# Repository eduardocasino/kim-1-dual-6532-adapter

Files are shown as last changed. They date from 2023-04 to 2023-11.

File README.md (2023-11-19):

# KIM-1 Dual 6530-6532 adapter

## Introduction

Welcome to the KIM-1 Dual 6530-6532 adapter repository. This adapter replaces both 6530 chips on the KIM-1 with a single board that contains a couple of 6532 chips, an EPROM and a few logic ICs.

As far as I know, this is the only board that allows you to replace both 6530 chips simultaneously.

## About

I designed this board for [my KIM-1 PCB replica](https://github.com/eduardocasino/kim-1), but it will also work with real KIM-1s that have both RRIOTs missing or broken.

The schematic is based on Ruud Baltissen's KIM-1 replica, with very minor modifications. The PCB features hand-traced tracks to seamlessly integrate with the KIM-1 board:

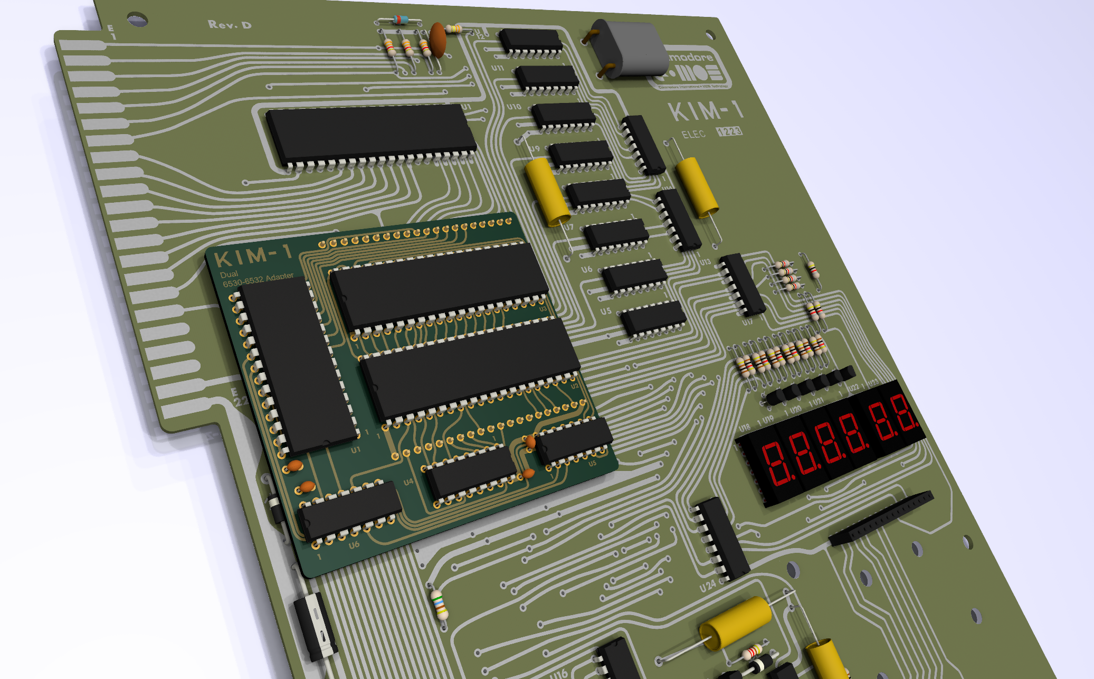
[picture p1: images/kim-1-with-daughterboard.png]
board installed


~~WARNING: I have not yet sent the board to fabrication, so it is untested!~~

The board has been successfully tested with my [my KIM-1 replica](https://github.com/eduardocasino/kim-1)

## Programming the EPROM

You can get the ROM contents from [Hans Otten's site](http://retro.hansotten.nl/6502-sbc/kim-1-manuals-and-software/kim_1-roms/)

There are two sets available: One that uses $00 as filler bytes and another that uses $FF. Both work equally well, but the one with $00 is what the original KIM-1 has. To program the EPROM:

1. Download "6530-002 fillerbyte00.bin" and "6530-003 fillerbyte00.bin" from Hans Otten's site (replace FF with 00 if you wish)
"6530-003 fillerbyte00.bin" has the ROM contents from $1800 to $1BFF and
"6530-002 fillerbyte00.bin" from $1C00 to $1FFF

2. Concat both files:

~~~
$ cat "6530-003 fillerbyte00.bin" "6530-002 fillerbyte00.bin" > KIM-1-ROM.bin
~~~

3. Program the EPROM with the resulting file starting at address $1800

## Licensing

This is a personal project that I am sharing in case it is of interest to any retrocomputing enthusiast and all the information in this repository is provided "as is", without warranty of any kind. I am not liable for any damages that may occur, whether it be to individuals, objects, KIM-1 computers, kittens or any other pets. It should also be noted that this design has not been tested and may contain errors, therefore anyone who chooses to use it does so at their own risk.



This work is licensed under a [Creative Commons Attribution-NonCommercial 4.0 International License](http://creativecommons.org/licenses/by-nc/4.0/).

EXCEPTION: The electrical schematic and all the associated symbols are licensed under a [Creative Commons Attribution 4.0 International License](https://creativecommons.org/licenses/by/4.0/).

See the LICENSE.md file for details.

## Changelog
#### 05/05/2023
* Fix tracks that were not well imported from svg
#### 09/04/2023
* Make ROM content available on phi2 only
* Add decoupling capacitor to ROM chip

## Acknowledgements

* Hans Otten and his [Retro Computing blog](http://retro.hansotten.nl/). Everything you need to know about the RRIOT and RIOT.
* Ruud Baltissen for [the original schematic](http://www.baltissen.org/newhtm/buildkim.htm).
* Frank Wolf and Dieter a.k.a. ttlworks for their [6530-004 dissection](http://forum.6502.org/viewtopic.php?f=4&t=6711) (Also [here](http://retro.hansotten.nl/6502-sbc/tim-6530-004/6530-004-dissected/)).

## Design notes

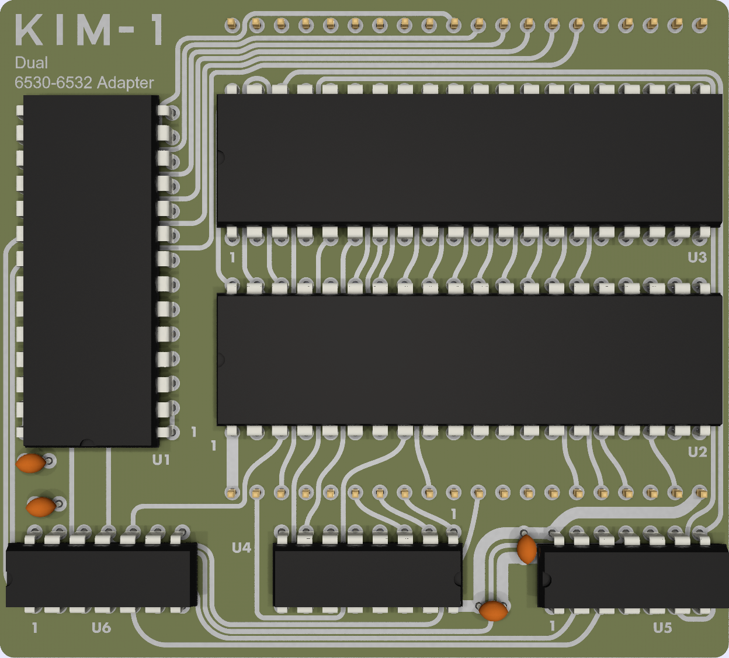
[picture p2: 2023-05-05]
images/kim-1-dual-6532-adapter-comp.png

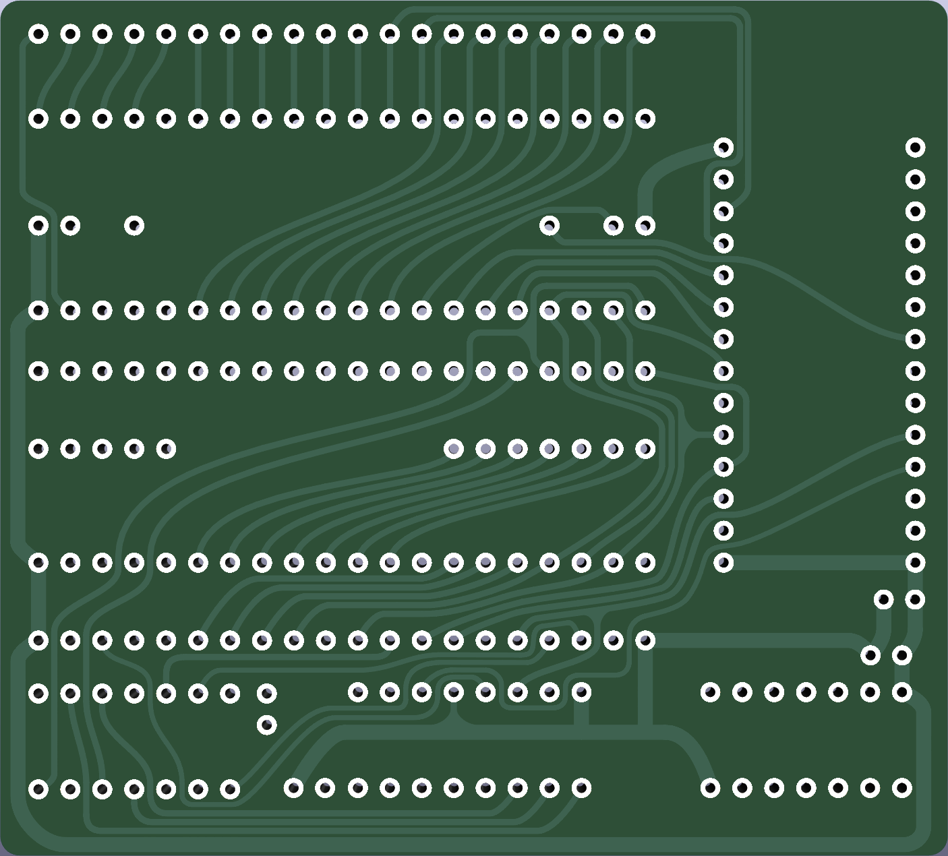
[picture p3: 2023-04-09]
images/kim-1-dual-6532-adapter-back.png

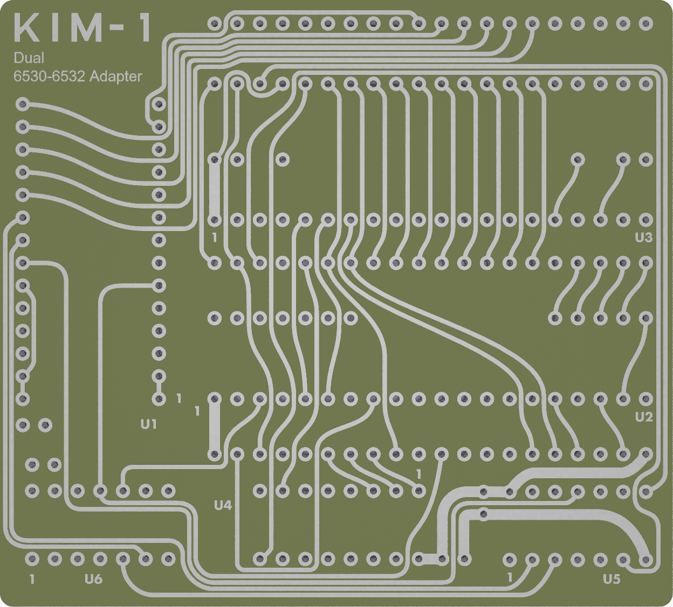
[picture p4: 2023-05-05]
images/kim-1-dual-6532-adapter-front.png

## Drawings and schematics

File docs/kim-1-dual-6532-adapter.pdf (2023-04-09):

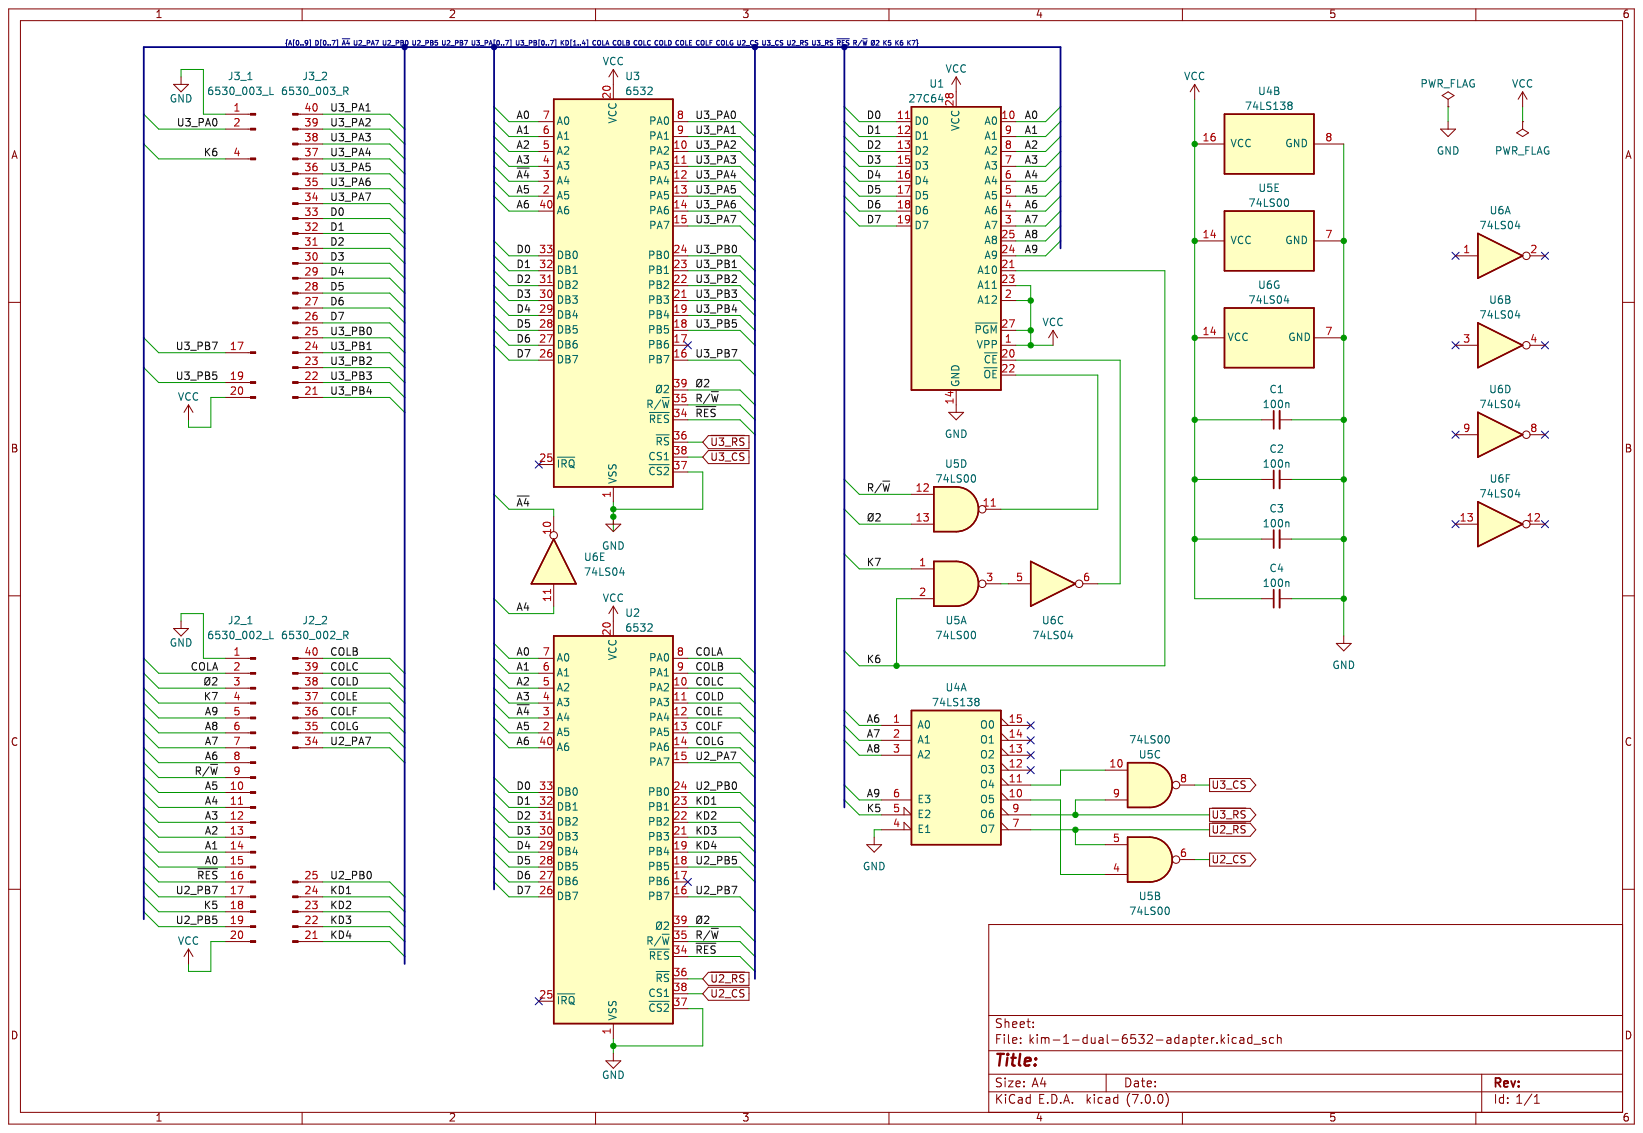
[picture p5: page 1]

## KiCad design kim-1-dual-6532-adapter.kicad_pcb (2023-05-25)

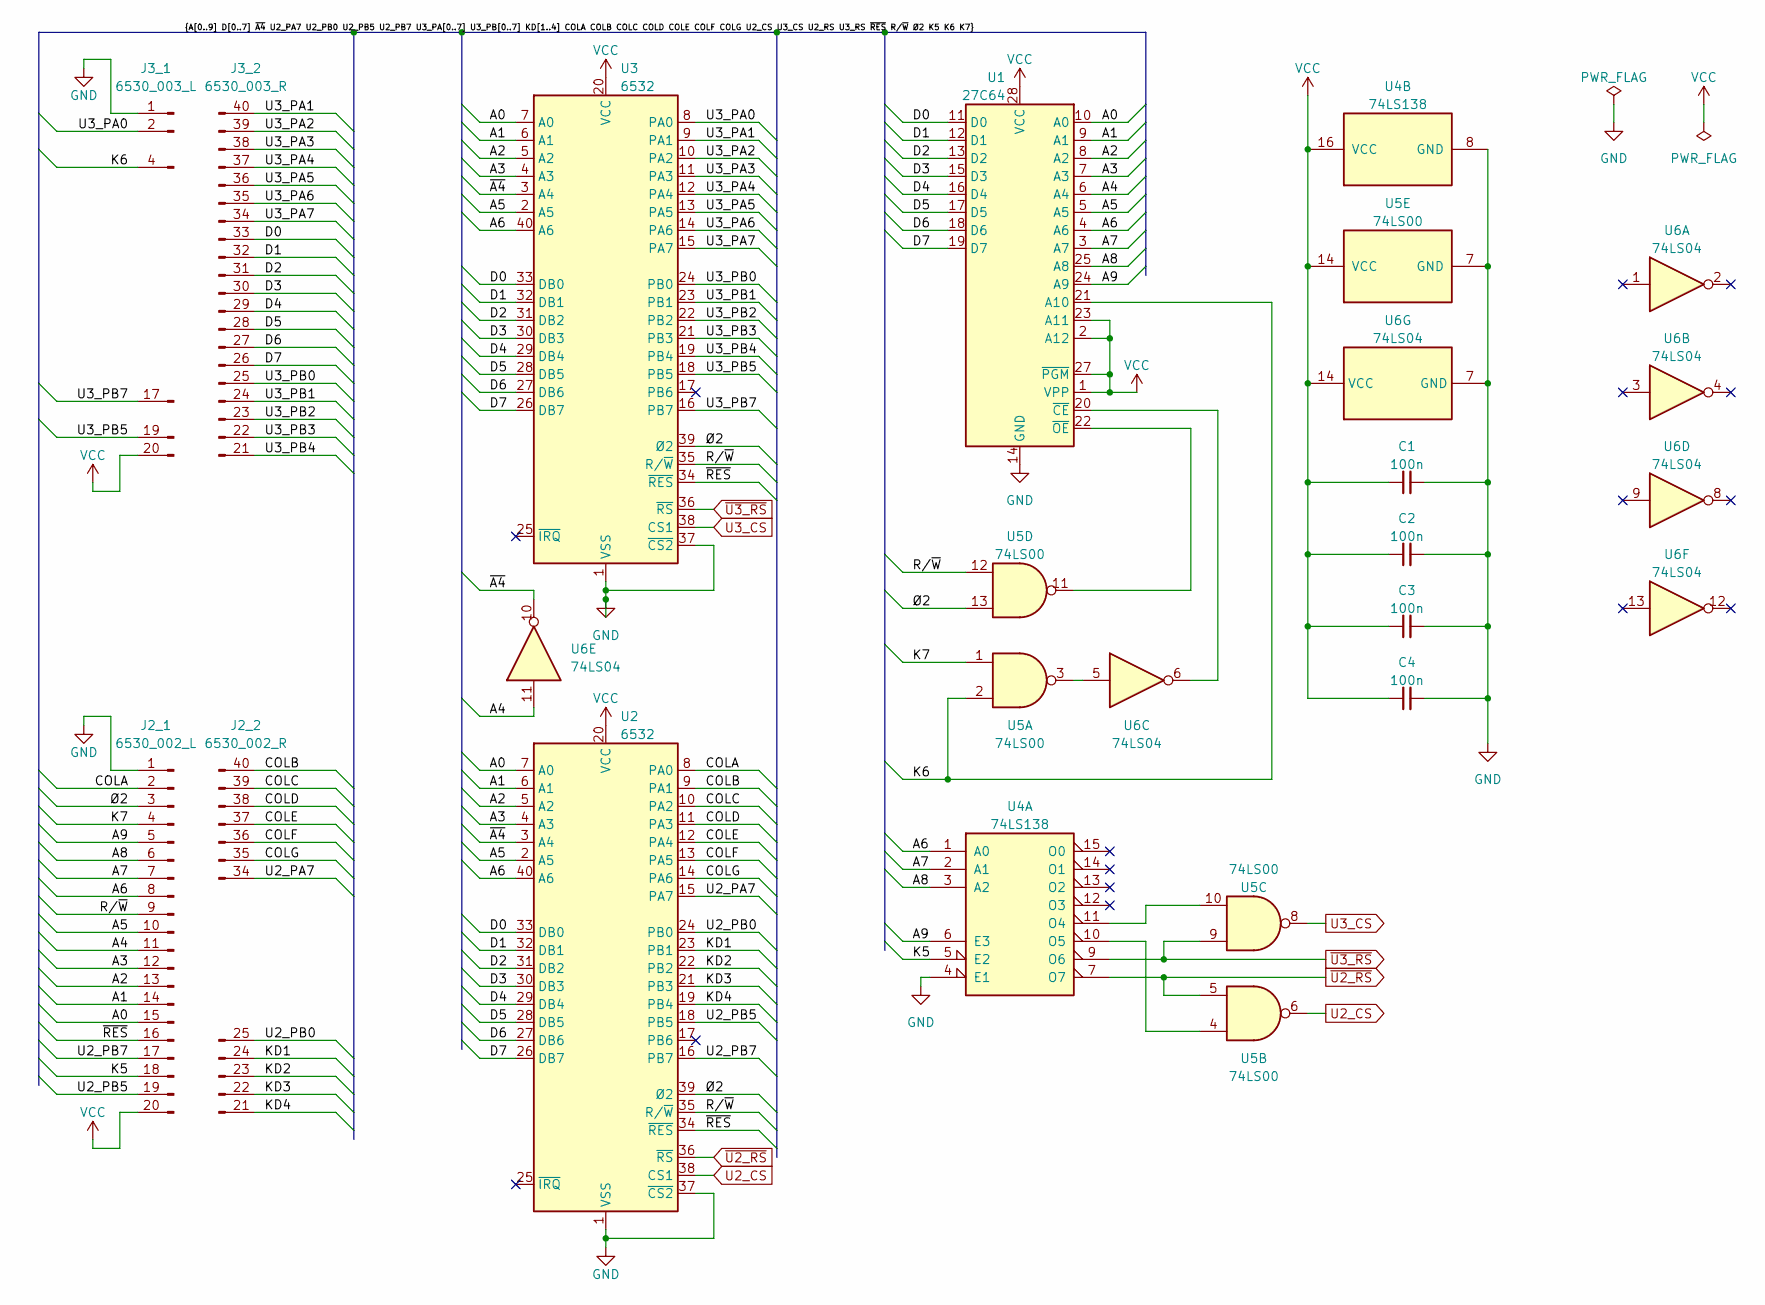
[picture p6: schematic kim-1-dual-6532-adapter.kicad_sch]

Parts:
C1, C2, C3, C4: 100n; C_Disc_D3.0mm_W2.0mm_P2.50mm
J2_1: 6530_002_L; PinHeader_1x20_A_P2.54mm_Vertical
J2_2: 6530_002_R; PinHeader_1x20_D_P2.54mm_Vertical
J3_1: 6530_003_L; PinHeader_1x20_C_P2.54mm_Vertical
J3_2: 6530_003_R; PinHeader_1x20_B_P2.54mm_Vertical
U1: 27C64; DIP-28_W15.24mm
U2, U3: 6532; DIP-40_W15.24mm
U4: 74LS138; DIP-16_W7.62mm
U5: 74LS00; DIP-14_W7.62mm
U6: 74LS04; DIP-14_W7.62mm

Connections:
/A0: J2_1.15, U1.10 (A0), U2.7 (A0), U3.7 (A0)
/A1: J2_1.14, U1.9 (A1), U2.6 (A1), U3.6 (A1)
/A2: J2_1.13, U1.8 (A2), U2.5 (A2), U3.5 (A2)
/A3: J2_1.12, U1.7 (A3), U2.4 (A3), U3.4 (A3)
/A4: J2_1.11, U1.6 (A4), U6.11
/A5: J2_1.10, U1.5 (A5), U2.2 (A5), U3.2 (A5)
/A6: J2_1.8, U1.4 (A6), U2.40 (A6), U3.40 (A6), U4.1 (A0)
/A7: J2_1.7, U1.3 (A7), U4.2 (A1)
/A8: J2_1.6, U1.25 (A8), U4.3 (A2)
/A9: J2_1.5, U1.24 (A9), U4.6 (E3)
/COLA: J2_1.2, U2.8 (PA0)
/COLB: J2_2.40, U2.9 (PA1)
/COLC: J2_2.39, U2.10 (PA2)
/COLD: J2_2.38, U2.11 (PA3)
/COLE: J2_2.37, U2.12 (PA4)
/COLF: J2_2.36, U2.13 (PA5)
/COLG: J2_2.35, U2.14 (PA6)
/D0: J3_2.33, U1.11 (D0), U2.33 (DB0), U3.33 (DB0)
/D1: J3_2.32, U1.12 (D1), U2.32 (DB1), U3.32 (DB1)
/D2: J3_2.31, U1.13 (D2), U2.31 (DB2), U3.31 (DB2)
/D3: J3_2.30, U1.15 (D3), U2.30 (DB3), U3.30 (DB3)
/D4: J3_2.29, U1.16 (D4), U2.29 (DB4), U3.29 (DB4)
/D5: J3_2.28, U1.17 (D5), U2.28 (DB5), U3.28 (DB5)
/D6: J3_2.27, U1.18 (D6), U2.27 (DB6), U3.27 (DB6)
/D7: J3_2.26, U1.19 (D7), U2.26 (DB7), U3.26 (DB7)
/K5: J2_1.18, U4.5 (E2)
/K6: J3_1.4, U1.21 (A10), U5.2
/K7: J2_1.4, U5.1
/KD1: J2_2.24, U2.23 (PB1)
/KD2: J2_2.23, U2.22 (PB2)
/KD3: J2_2.22, U2.21 (PB3)
/KD4: J2_2.21, U2.19 (PB4)
/R/~W: J2_1.9, U2.35 (R/~W), U3.35 (R/~W), U5.12
/U2_PA7: J2_2.34, U2.15 (PA7)
/U2_PB0: J2_2.25, U2.24 (PB0)
/U2_PB5: J2_1.19, U2.18 (PB5)
/U2_PB7: J2_1.17, U2.16 (PB7)
/U3_PA0: J3_1.2, U3.8 (PA0)
/U3_PA1: J3_2.40, U3.9 (PA1)
/U3_PA2: J3_2.39, U3.10 (PA2)
/U3_PA3: J3_2.38, U3.11 (PA3)
/U3_PA4: J3_2.37, U3.12 (PA4)
/U3_PA5: J3_2.36, U3.13 (PA5)
/U3_PA6: J3_2.35, U3.14 (PA6)
/U3_PA7: J3_2.34, U3.15 (PA7)
/U3_PB0: J3_2.25, U3.24 (PB0)
/U3_PB1: J3_2.24, U3.23 (PB1)
/U3_PB2: J3_2.23, U3.22 (PB2)
/U3_PB3: J3_2.22, U3.21 (PB3)
/U3_PB4: J3_2.21, U3.19 (PB4)
/U3_PB5: J3_1.19, U3.18 (PB5)
/U3_PB7: J3_1.17, U3.16 (PB7)
/~A4: U2.3 (A4), U3.3 (A4), U6.10
/~RES: J2_1.16, U2.34 (~RES), U3.34 (~RES)
/Ø2: J2_1.3, U2.39 (Ø2), U3.39 (Ø2), U5.13
GND: C1.2, C2.2, C3.2, C4.2, J2_1.1, J3_1.1, U1.14 (GND), U2.1 (VSS), U2.37 (~CS2), U3.1 (VSS), U3.37 (~CS2), U4.4 (E1), U4.8 (GND), U5.7 (GND), U6.7 (GND)
unnamed: U1.20 (~CE), U6.6
unnamed: U1.22 (~OE), U5.11
unnamed: U4.11 (O4), U5.10
unnamed: U4.10 (O5), U5.4
unnamed: U5.3, U6.5
U2_CS: U2.38 (CS1), U5.6
U3_CS: U3.38 (CS1), U5.8
VCC: C1.1, C2.1, C3.1, C4.1, J2_1.20, J3_1.20, U1.1 (VPP), U1.2 (A12), U1.23 (A11), U1.27 (~PGM), U1.28 (VCC), U2.20 (VCC), U3.20 (VCC), U4.16 (VCC), U5.14 (VCC), U6.14 (VCC)
~U2_RS: U2.36 (~RS), U4.7 (O7), U5.5
~U3_RS: U3.36 (~RS), U4.9 (O6), U5.9

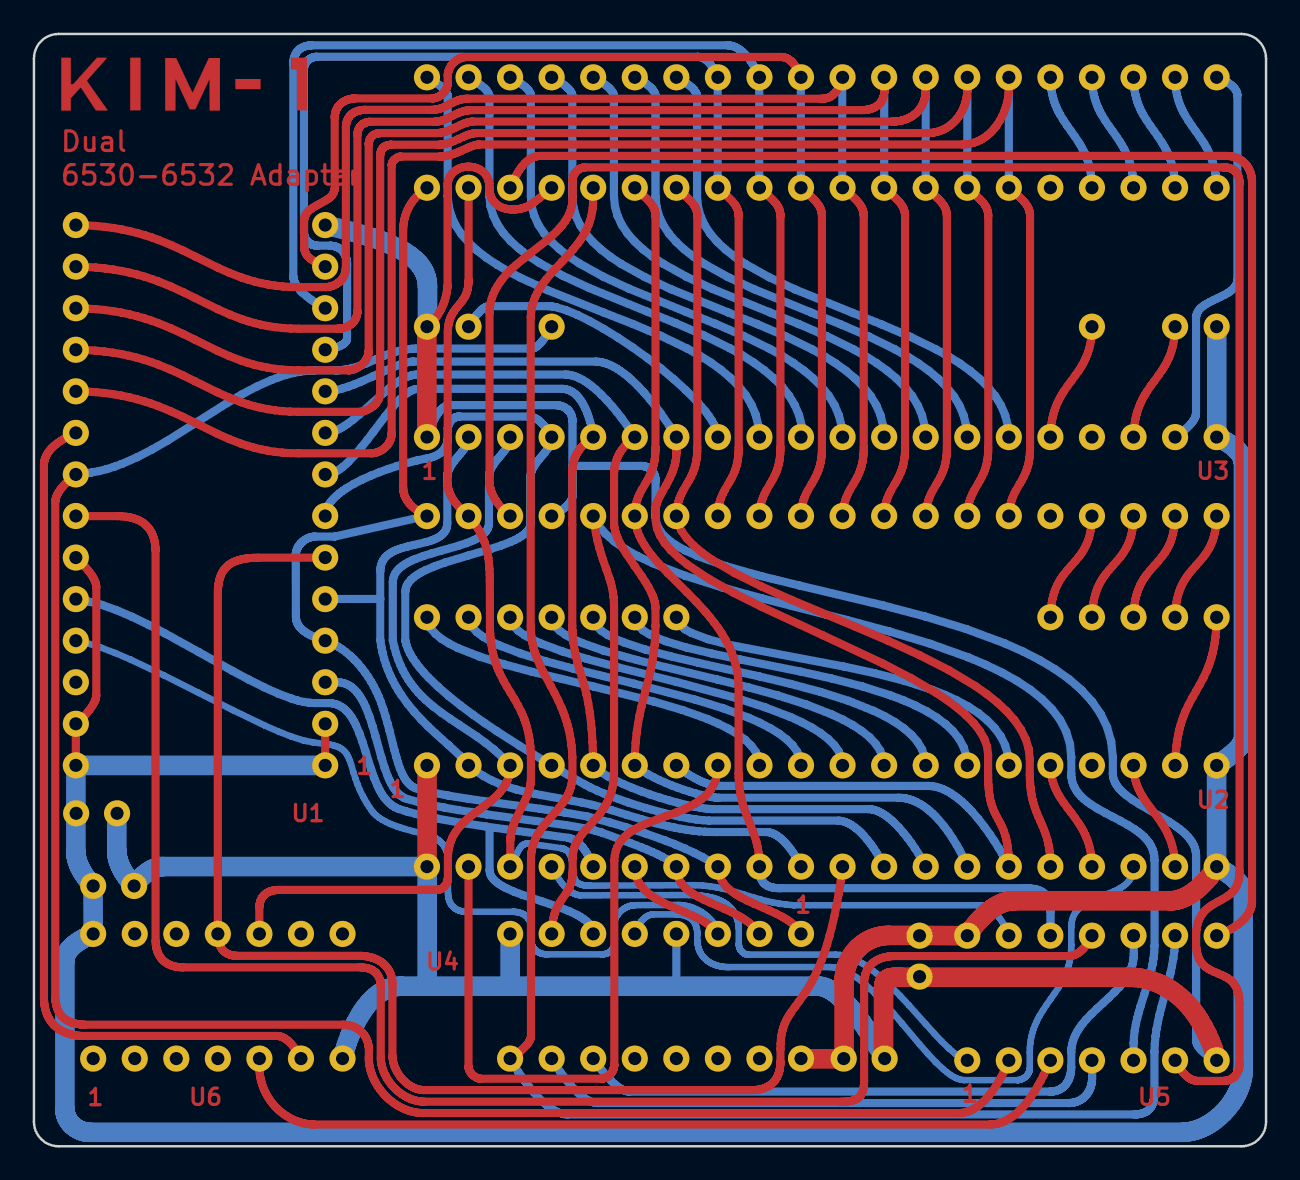
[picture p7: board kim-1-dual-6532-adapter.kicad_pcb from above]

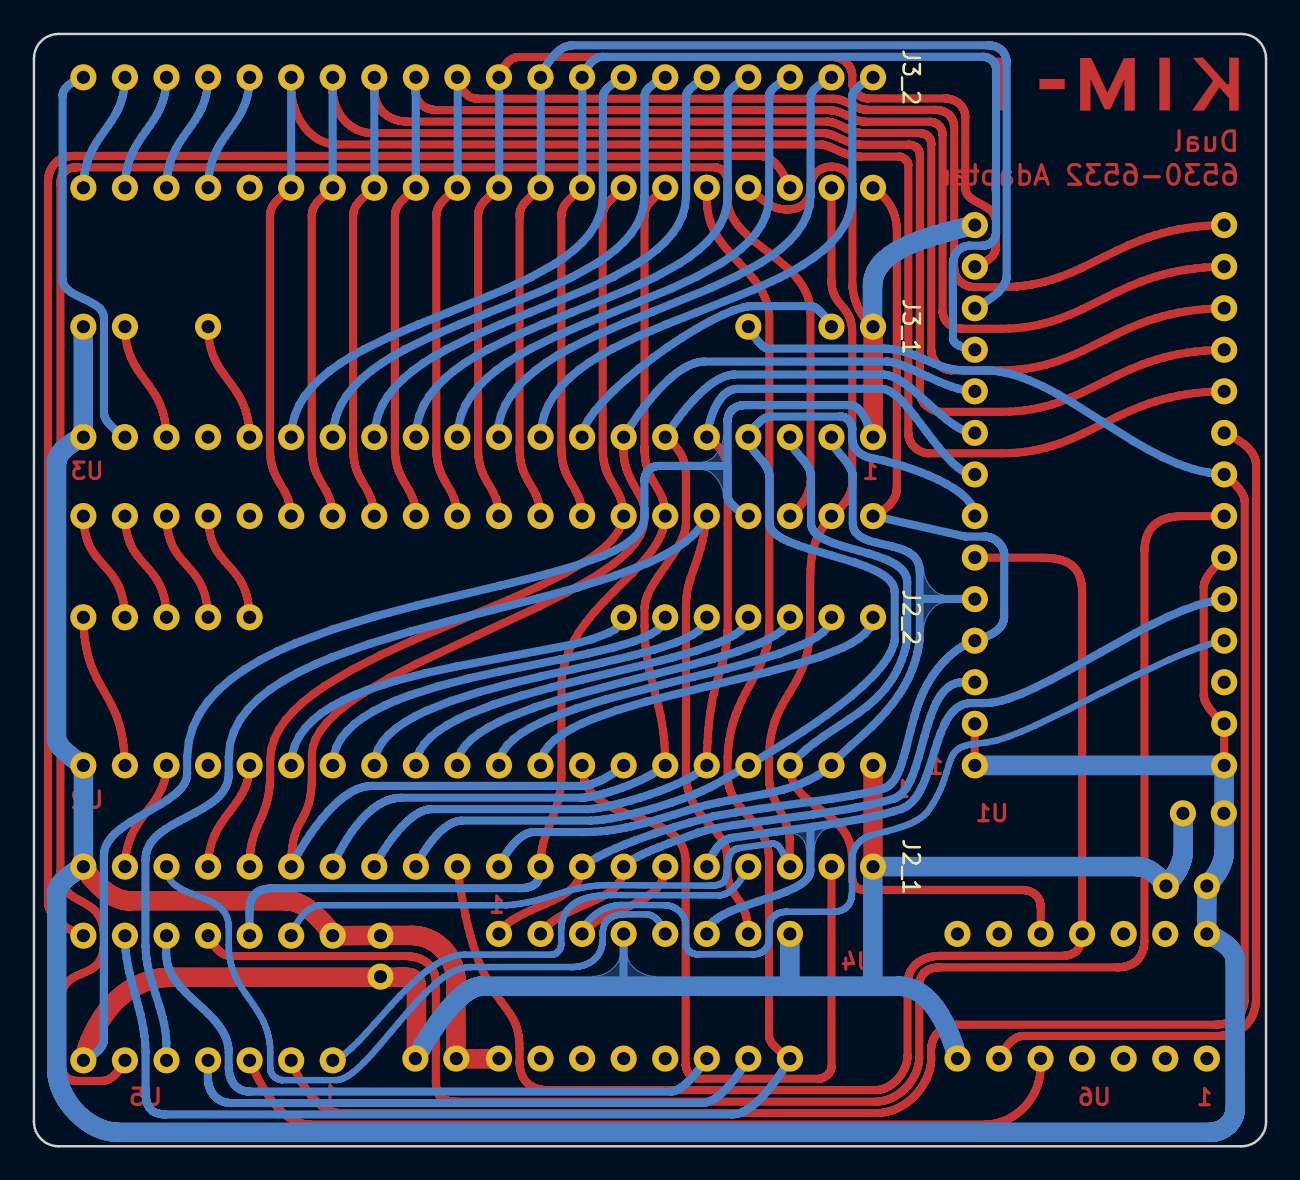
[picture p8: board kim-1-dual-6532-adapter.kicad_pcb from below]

Board: 2 copper layers, 75.3 x 68.0 mm, 15 parts (4 on the bottom side), 66 nets.

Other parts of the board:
Ref**: Val**; KIM-1_Logo

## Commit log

2023-04-05 Adjust some references
    [kim-1-dual-6532-adapter.kicad_sch]
2023-04-09 Control ROM's OE with phi2
    [kim-1-dual-6532-adapter.kicad_pcb, kim-1-dual-6532-adapter.kicad_sch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]
2023-05-05 Fix tracks that were not well imported from svg
    [kim-1-dual-6532-adapter.kicad_pcb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]
2023-05-25 Generate correct gerber files format
    [kim-1-dual-6532-adapter-B_Mask.gbs, kim-1-dual-6532-adapter-B_Paste.gbp, kim-1-dual-6532-adapter-Bottom.gbl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]
2023-08-03 Update board status

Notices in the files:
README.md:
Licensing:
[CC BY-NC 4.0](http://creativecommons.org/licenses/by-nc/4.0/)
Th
